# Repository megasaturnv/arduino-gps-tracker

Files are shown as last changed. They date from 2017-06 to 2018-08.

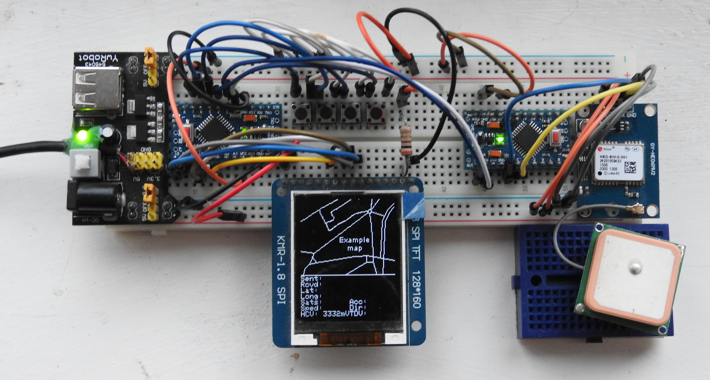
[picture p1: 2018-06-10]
docs/top down view.jpg

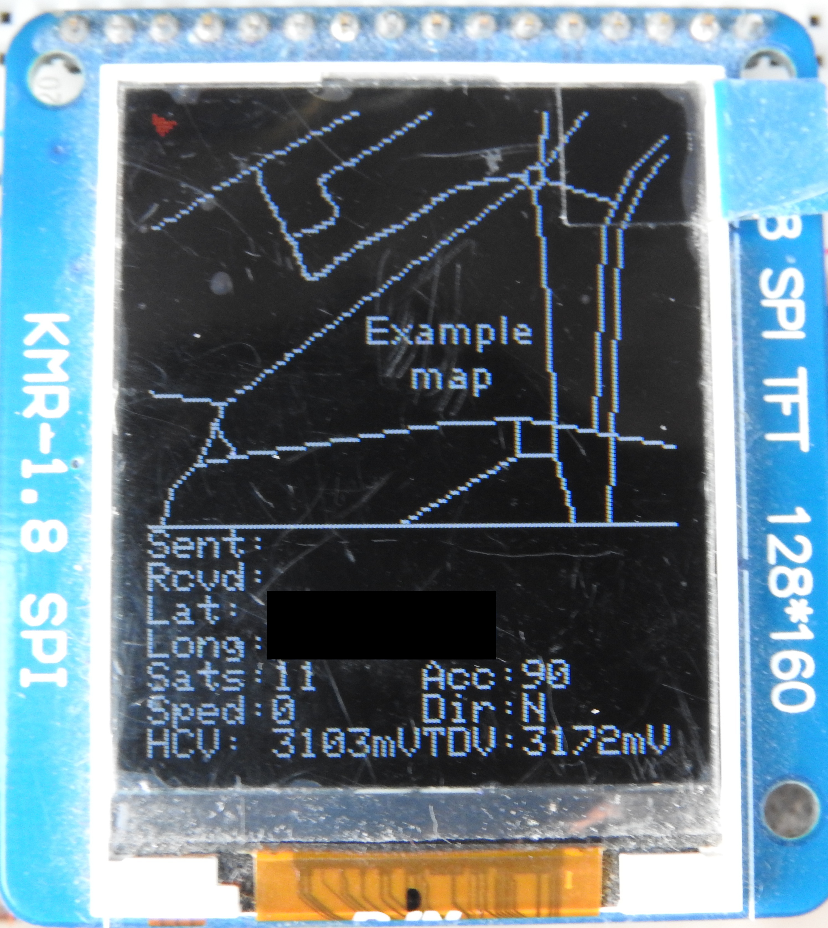
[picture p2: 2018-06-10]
docs/Location marker on Screen.jpg

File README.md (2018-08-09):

# arduino-gps-tracker
## Synopsis
An Arduino-based GPS tracking solution. One Arduino and Ublox Neo-6m (GY-NEO6MV2) GPS module on stripboard / veroboard is used as the GPS tracking device. The other is an Arduino handheld controller which requests information from the tracking device and displays the coordinates, GPS location and location on a map. By default, the display is a 128x160 1.8" TFT LCD but the code can be adapted for other displays. Communication occurs between the two devices with the HC-12 wireless serial communication module. This project can be adapted to use other methods of wireless communication such as the XBee or GSM mobile network. Please make sure the frequency used and transmitting power is legal in your country.



## Description of Arduino handheld controller
The Arduino handheld controller is used by a user to find the location of their GPS tracking device. It is powered by an 18650 Li-ion cell and consists of Li-ion protection and charging circuitry, an Arduino, a 1.8" TFT LCD display, a HC-12 wireless communication module and buttons for requesting various data from the tracking device. When it receives data from the tracking device, the Arduino will interpret the message formtted as \<datatype>:\<CSV of data> into \<data type> and an array of data for each item in \<CSV of data>. Then, the tracker respond in the appropriate way. The messages it understands and the way it responds are listed below:

#### if receive "volts:\[millivolts\]"
Display the tracking device Arduino's VCC voltage on the 1.8" TFT LCD display.

#### if receive "gps:\<latitude>, \<longitude>, \<num of satellites>, \<accuracy>, \<speed>, \<direction>, \<age of data>, \<checksum>"
Display these figures on the 1.8" TFT LCD display.

### Buttons
The buttons on the handheld controller are pulled high by the Arduino's internal pull-up resistors. To activate the button, the pin should be connected to ground. 

### The Arduino pins used to connect to peripherals is shown below:
#define name | Pin no. | Function
--- | --- | ---
SOFTWARE_SERIAL_TX | 2 | For the HC-12 module. Connects to HC-12 RX
SOFTWARE_SERIAL_RX | 3 | For the HC-12 module. Connects to HC-12 TX
CELLVOLTS_BUTTON | 4 | Push button connected to ground. transmit: "cell:volts" to the tracking device
REQUEST_GPS_ONCE_BUTTON | 5 | Push button connected to ground. transmit: "gps:once"
REQUEST_GPS_CONTINUOUS_BUTTON | 6 | Push button connected to ground. transmit: "gps:continuous"
REQUEST_GPS_STOP_BUTTON | 7 | Push button connected to ground. transmit: "gps:stop"
sclk | 13 | Connection to 1.8" TFT LCD screen. Connects to TFT SCK/
mosi | 11 | Connection to 1.8" TFT LCD screen. Connects to TFT SDA/
cs | 10 | Connection to 1.8" TFT LCD screen. Connects to TFT SCS/
dc | A0 | Connection to 1.8" TFT LCD screen. Connects to TFT A0/
rst | A1 | Connection to 1.8" TFT LCD screen. Connects to TFT RESET/

### Showing location on the display's map
*COMING SOON*

### How to create your own maps for the TFT LCD screen
*COMING SOON*

## Description of Arduino GPS tracking device
The Arduino tracking device should be attached to an object which the user wants to track. It is powered by an 18650 Li-ion cell and consists of Li-ion protection and charging circuitry, an Arduino, a Ublox Neo-6m (GY-NEO6MV2) GPS module and a HC-12 wireless communication module. The circuit is built onto a piece of stripboard / veroboard. When powered, the Arduino will go into a light sleep mode. It will wake up when it receives serial data from the HC-12 module. The Arduino will interpret the message formtted as \<datatype>:\<CSV of data> into \<data type> and an array of data for each item in \<CSV of data>. Then, the tracker responds in the appropriate way.

### Kicad designs



### The messages the Arduino GPS tracking device understands and the way it responds are listed below:
#### if receive "cell:volts"
send "cell:\[millivolts\]" where millivolts = voltage of the tracking device Arduino's VCC pin

#### if receive "gps:once"
send "message:received gps once" and try to get GPS coordinates. Then, send coordinates once and go to sleep

#### if receive "gps:continuous"
send "message:received gps continuous" and try to get GPS coordinates. Then, send coordinates every 10 seconds

#### if receive "gps:stopcontinuous"
send "message:gpsstopcontinuous" and then stop sending GPS coordinates continuously

If the tracking device is requested for coordinates, it will try and get its GPS location. If it cannot get a fix after GPS_TIMEOUT milliseconds, the Arduino will send "message:Unable to get GPS fix" to the handheld controller, where it will be displayed on the screen. This functionality can be disabled by setting GPS_TIMEOUT to 0 (#define GPS_TIMEOUT 0).

If no more GPS coordinates are required (after a successful GPS lock with "gps:once" or "gps:stopcontinuous" commmand) or if the Arduino has been on for more than MAX_ON_TIME, go to sleep. MAX_ON_TIME is a failsafe to make sure the Arduino doesn't stay on for more than MAX_ON_TIME milliseconds. This functionality can be disabled by setting MAX_ON_TIME to 0 (#define MAX_ON_TIME 0).

### The Arduino pins used to connect to peripherals is shown below:

Pin description | Pin no. | Function
--- | --- | ---
SERIAL_UART_RX | 0 | For the HC-12 module. Connects to HC-12 TX
SERIAL_UART_TX | 1 | For the HC-12 module. Connects to HC-12 RX

#define name | Pin no. | Function
--- | --- | ---
SOFTWARE_SERIAL_RX | 3 | Software serial RX pin, to be connected to the GPS module's TX
SOFTWARE_SERIAL_TX | 2 | Software serial TX pin, to be connected to the GPS module's RX

## Motivation
I have created this project to be used as a dog tracker, but it can easily track a car and other valuable item.

## Installation
Upload gpsTracker_handheldController to the Arduino which will be used in the handheld controller. Upload gpsTracker_trackingDevice to the Arduino which will be used in the tracking device. Follow the build diagrams and create the stripboard / veroboard circuit board from the KiCAD files to construct the GPS tracking device.

## Libraries used
### Handheld controller
* [Adafruit_GFX](https://github.com/adafruit/Adafruit-GFX-Library)
* [Adafruit_QDTech](https://github.com/zigwart/Adafruit_QDTech) Note my display is QDTech 1.8" 128x160 pixel LCD board using a Samsung S6D02A1 chip, so I need a special library.
* [SPI](https://github.com/arduino/Arduino/tree/master/hardware/arduino/avr/libraries/SPI)
* [SoftwareSerial](https://github.com/arduino/Arduino/tree/master/hardware/arduino/avr/libraries/SoftwareSerial)

### Tracking device
* [avr/power](https://github.com/Synapseware/avr/blob/master/include/avr/power.h)
* [avr/sleep](https://github.com/Synapseware/avr/blob/master/include/avr/sleep.h)
* [SoftwareSerial](https://github.com/arduino/Arduino/tree/master/hardware/arduino/avr/libraries/SoftwareSerial)
* [TinyGPS](http://arduiniana.org/libraries/tinygps/)

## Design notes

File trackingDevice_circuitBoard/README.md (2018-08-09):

# gpsTracker_trackingDevice_circuitBoard
Schematic and circuit board design for the tracking device. Used to create a stripboard / veroboard circuit board.

To be opened with KiCad EDA, a cross platform, free and open source electronics design automation suite.
* http://kicad-pcb.org/
* https://github.com/kicad

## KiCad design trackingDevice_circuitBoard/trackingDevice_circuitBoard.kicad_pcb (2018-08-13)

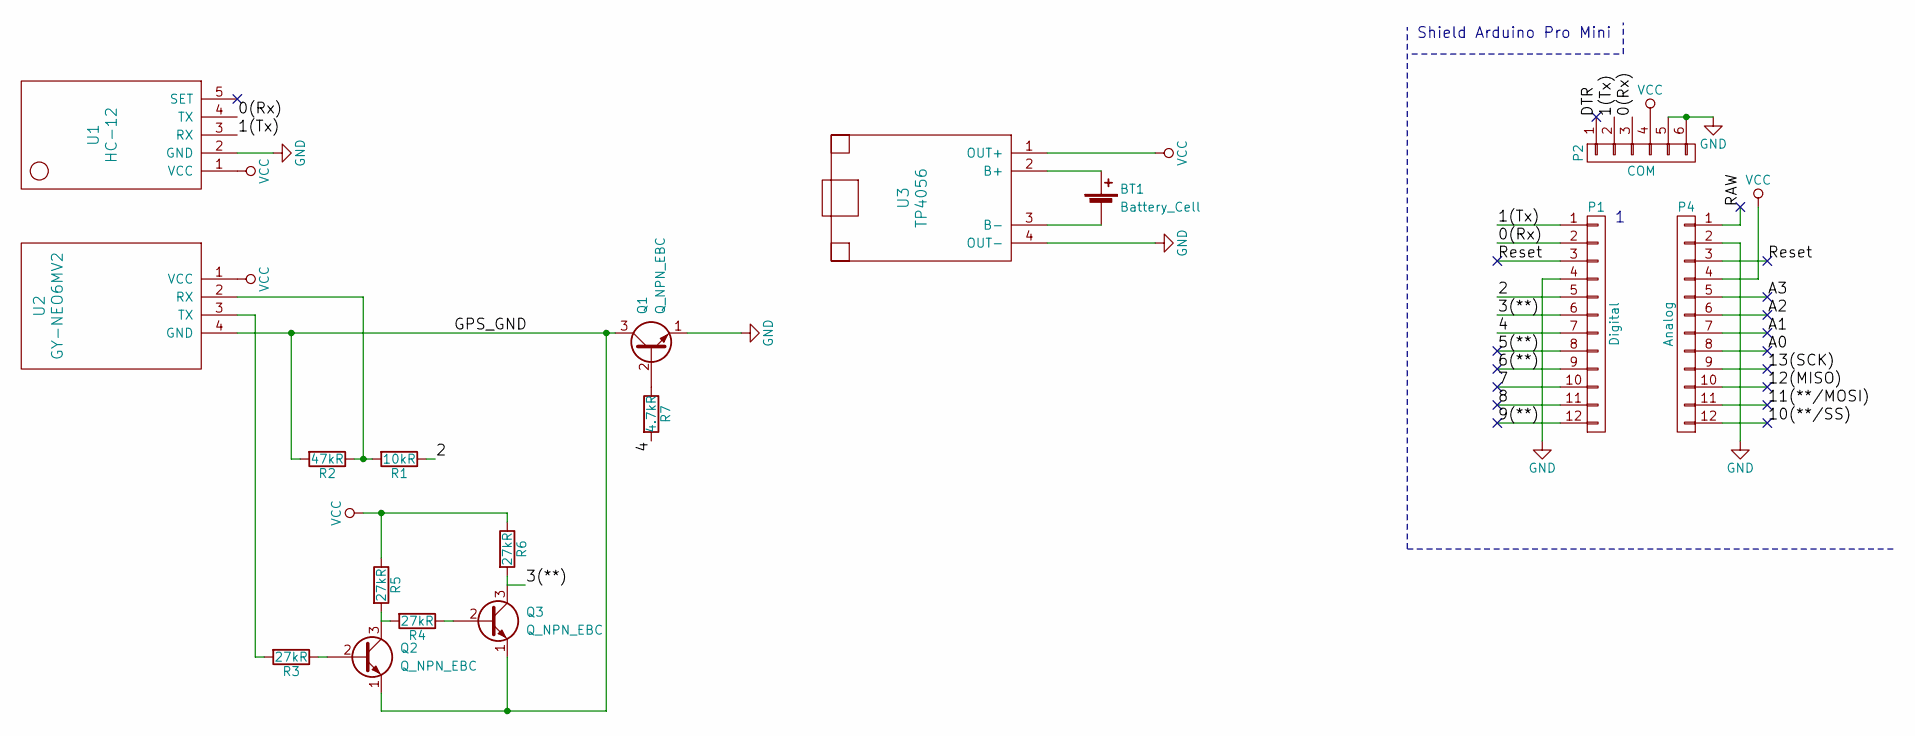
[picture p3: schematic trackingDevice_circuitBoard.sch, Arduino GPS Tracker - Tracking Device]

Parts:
BT1: Battery_Cell; CP_Axial_L67.0mm_D23.0mm_P75.00mm_Horizontal
P1: Digital; Socket_Strip_Straight_1x12_Pitch2.54mm
P2: COM
P4: Analog; Socket_Strip_Straight_1x12_Pitch2.54mm
Q1, Q2, Q3: Q_NPN_EBC; TO-92_Inline_Wide
R1: 10kR; R_Axial_DIN0207_L6.3mm_D2.5mm_P10.16mm_Horizontal
R2: 47kR; R_Axial_DIN0207_L6.3mm_D2.5mm_P10.16mm_Horizontal
R3, R4, R5, R6: 27kR; R_Axial_DIN0207_L6.3mm_D2.5mm_P10.16mm_Horizontal
R7: 4.7kR; R_Axial_DIN0207_L6.3mm_D2.5mm_P15.24mm_Horizontal
U1: HC-12; Socket_Strip_Straight_1x05_Pitch2.54mm
U2: GY-NEO6MV2; Socket_Strip_Straight_1x04_Pitch2.54mm
U3: TP4056; TP4056_with_protection

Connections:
/0(Rx): P1.2, P2.3, U1.4 (TX)
/1(Tx): P1.1, P2.2, U1.3 (RX)
/2: P1.5, R1.1
/3(**): P1.6, Q3.3 (C), R6.2
/4: P1.7, R7.2
/5(**): P1.8
/6(**): P1.9
/7: P1.10
/8: P1.11
/9(**): P1.12
/10(**/SS): P4.12
/11(**/MOSI): P4.11
/12(MISO): P4.10
/13(SCK): P4.9
/A0: P4.8
/A1: P4.7
/A2: P4.6
/A3: P4.5
/GPS_GND: Q1.3 (C), Q2.1 (E), Q3.1 (E), R2.2, U2.4 (GND)
/RAW: P4.1
/Reset: P1.3, P4.3
GND: P1.4, P2.5, P2.6, P4.2, Q1.1 (E), U1.2 (GND), U3.4 (OUT-)
unnamed: BT1.1 (+), U3.2 (B+)
unnamed: BT1.2 (-), U3.3 (B-)
unnamed: Q1.2 (B), R7.1
unnamed: Q2.2 (B), R3.1
unnamed: Q2.3 (C), R4.2, R5.2
unnamed: Q3.2 (B), R4.1
unnamed: R1.2, R2.1, U2.2 (RX)
unnamed: R3.2, U2.3 (TX)
VCC: P2.4, P4.4, R5.1, R6.1, U1.1 (VCC), U2.1 (VCC), U3.1 (OUT+)

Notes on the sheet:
Shield Arduino Pro Mini

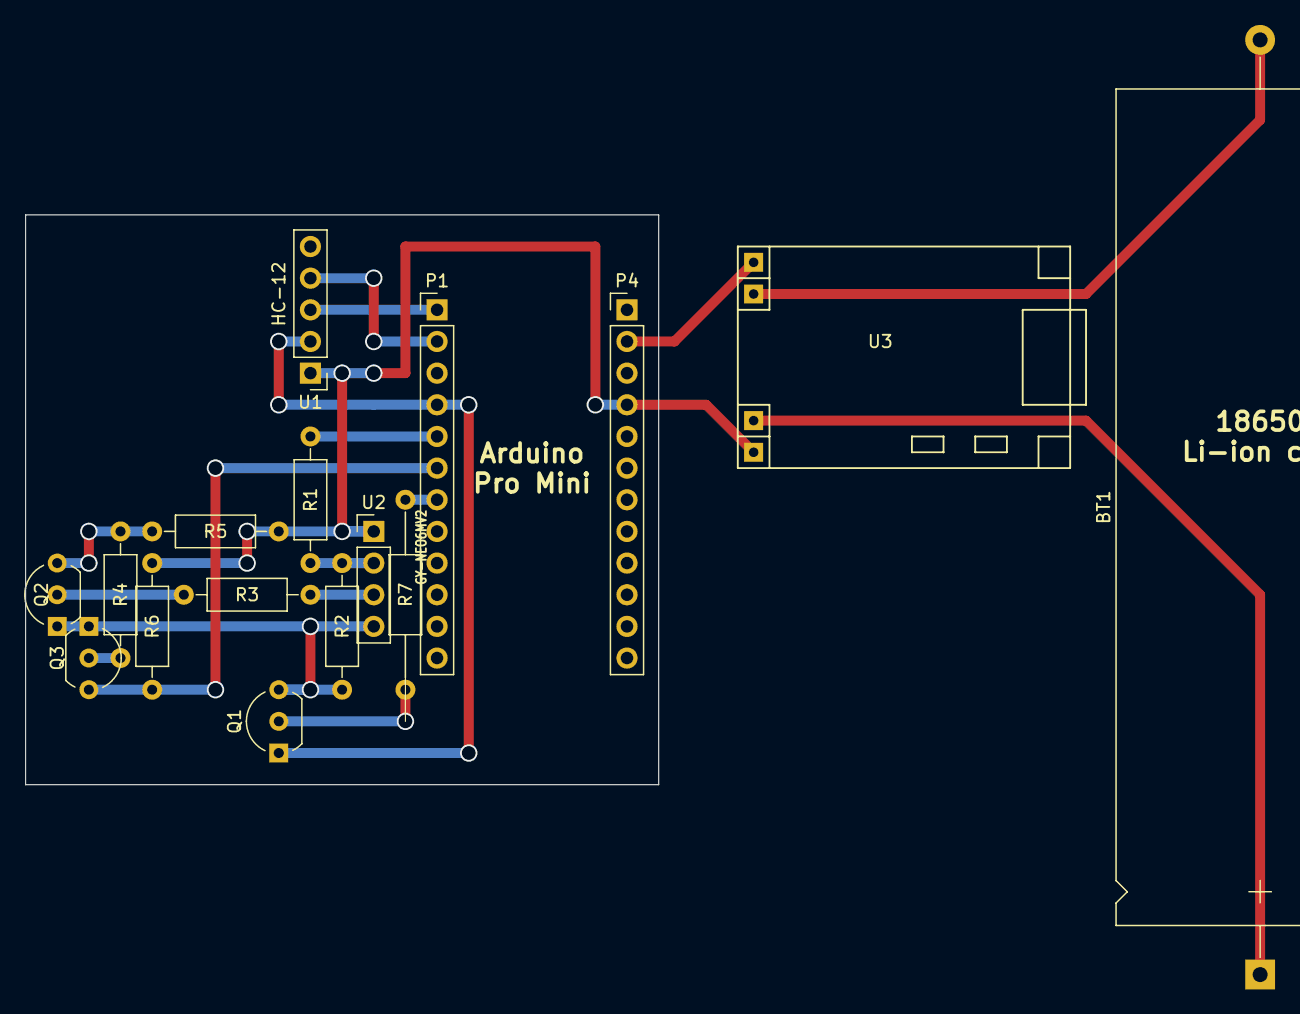
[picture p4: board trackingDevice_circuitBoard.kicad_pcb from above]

Board: 2 copper layers, 50.8 x 45.7 mm, 16 parts (0 on the bottom side), 17 nets.

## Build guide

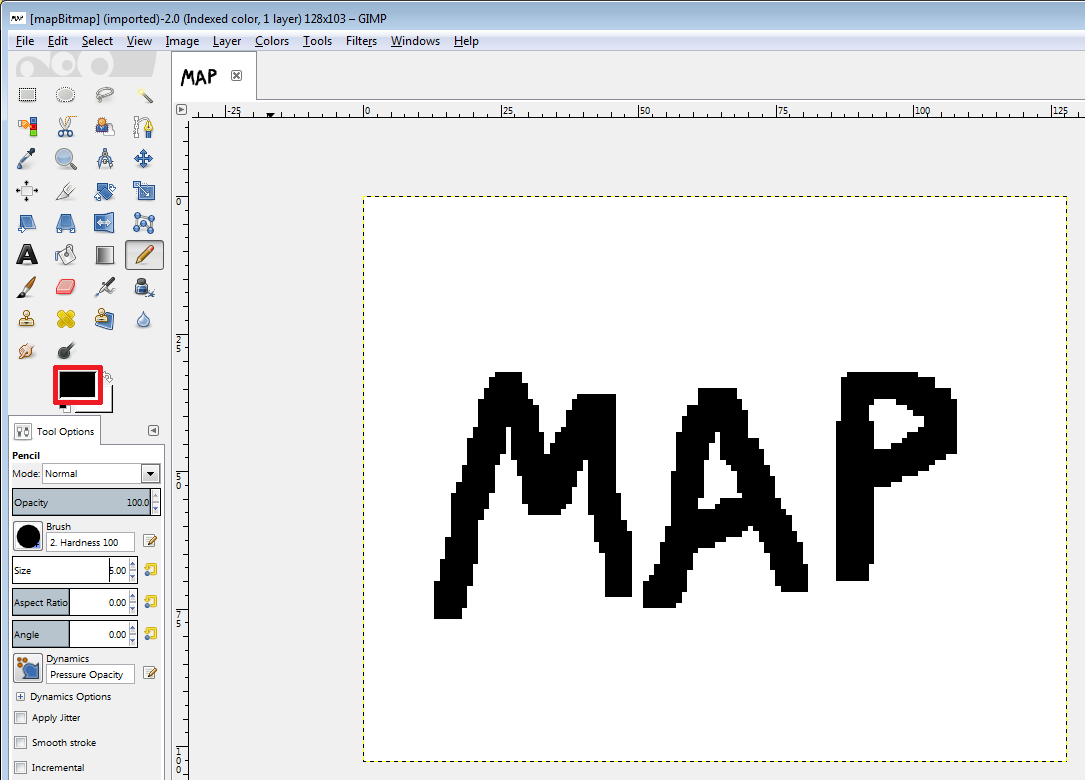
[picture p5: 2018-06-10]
maps/Step3 Draw your map.png

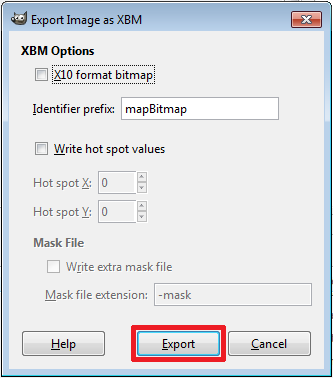
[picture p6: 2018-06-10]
maps/Step6 Export Settings2.png

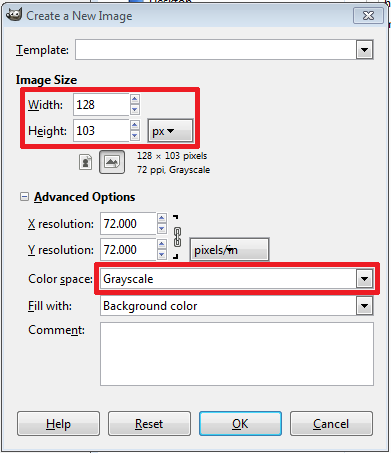
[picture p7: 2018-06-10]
maps/Step2 New Image Settings.png

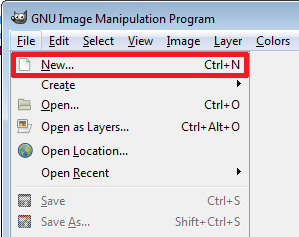
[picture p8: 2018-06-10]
maps/Step1 New Image.png

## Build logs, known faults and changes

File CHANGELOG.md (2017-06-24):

# arduino-gps-tracker changelog
## v0.1
* Initial release
* Handheld controller: Added the handheld controller under "gpsTracker_handheldController". It can display sent messages, received messages, latitude, longitude, number of satellites, accuracy, speed, direction, age of data and the checksum value.
* Handheld controller: Added map to TFT LCD screen. Map is not yet functional.
* Tracking device: Added the GPS tracker under "gpsTracker_trackingDevice". It can get GPS coordinates and transmit them when requested.
* Tracking device: Added code so the Arduino can go into a light sleep and wake up when serial data in the buffer. Sleep occurs after the Arduino has finished its task, couldn't receive coordinates before GPS_TIMEOUT milliseconds or, as a failsafe, the Arduino will sleep if it has been on for more than MAX_ON_TIME milliseconds as long as it hasn't received any messages from the handheld controller during this time.

## v0.2
* Handheld controller: Added ability to show the current location on the map
* Handheld controller: The program requires the max and min values of latitude and longitude covered by the map
* Handheld controller: Added 3 functions: clearTFTMAP(), drawTFTMap() and displayLocationOnMap(currentLatitude,currentLongitude)
* Handheld controller: Removed debugging code from gpsTracker_handheldController which printed to the UART Serial port
* Handheld controller: Renamed some functions and variables for clarity
* Tracking device: Renamed some functions and variables for clarity
* Tracking device: Tweaked delay values for better timing

## v0.2.1
* Handheld controller: Added clear map button on pin 8

## v0.3
* Handheld controller: Renamed LED_BUILTIN to LED_PIN and changed value to pin 9. Pin 13 is used by the TFT LCD screen
* Handheld controller: Changed the way location is drawn on the map (from 5 pixels in a '+' shape to a single pixel)
* Handheld controller: Added functionality to draw a green line to represent the tracker's location history
* Handheld controller test code: Added test code for drawing arrows on the screen
* Handheld controller: Added ability to draw an arrow at the edge of the screen if the tracker is outside the map
* Tracking device: Increased default MAX_ON_TIME to 1 hour

## v0.3.1
* Handheld controller: Added more constants under #define, for custom configurations

## v0.3.2
* Tracking device: Added KiCad circuit board files to "/gpsTracker_trackingDevice_circuitBoard/"

## v0.3.3
* Tracking device: Added more configuration constants
* Tracking device: Fixed bug where Arduino should stay awake to report continuous GPS data but would instead sleep if any message was received on the UART serial buffer
* Tracking device: Added more code comments

## v0.3.4
* Tracking device: Added ability for Arduino to control the GPS's power through pin 4. An N-channel MOSFET is required. See circuit diagram in gpsTracker_trackingDevice_circuitBoard/
* Tracking device: Updated OutputPowerSavingPins[] array to reflect changes

## v0.4
* Tracking device: Added readVcc() function which allows the Arduino to read its own Vcc input voltage. This will allow the user to know the charge state of the Li-ion cell(s)
* Tracking device: Tracking device will return cell charge in mV as: "cell:0000mV" when it receives "cell:volts"
* Tracking device: Removed "ping" message recognition code
* Handheld controller: Replaced ping button with cell voltage button
* Handheld controller: Removed "ping" message recognition code
* Handheld controller: Removed "age" and "check" areas from screen to make room for HCV:0000mV (Handheld controller voltage) and TDV:0000mV (Tracking device voltage)
* Handheld controller: Moved bottom-right values to the left by 1 character (6 pixels) to give more room for values
* Handheld controller: Modified clearTFTGPS(). Added clearTFT_HCV() and clearTFT_TDV()
* Handheld controller: Added code so the handheld controller can request and display the Vcc voltage of the GPS tracking device
* Handheld controller: Also added readVcc() function which allows the Arduino to read its own Vcc input voltage
* Handheld controller: Added code so the handheld controller reads its own Vcc input voltage every HCV_READVCC_INTERVAL in milliseconds and displays value on TFT screen. default HCV_READVCC_INTERVAL is 30000 ms
* Handheld controller: Removed unused functions
* Tracking device: Renamed GPS_DATA_TRANSMIT_FREQUENCY to GPS_DATA_TRANSMIT_INTERVAL for clarity
* Tracking device: Removed unused functions

## v0.4.1 (Current release)
* Handheld controller: Renamed files and folders to remove "gpsTracker_..."
* Tracking device: Renamed files and folders to remove "gpsTracker_..."

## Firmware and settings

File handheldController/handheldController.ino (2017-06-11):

#define MAP_WIDTH_PX 128 // Height of the map on the screen in pixels
#define MAP_HEIGHT_PX 103 // Width of the map on the screen in pixels

#define MAP_MIN_LAT  51.49933 // Bottom of map
#define MAP_MAX_LAT  51.50922 // Top of map
#define MAP_MIN_LONG -0.14816 // Left of map
#define MAP_MAX_LONG -0.12059 // Right of map

#define COLOUR_BACKGROUND QDTech_BLACK // Display background colour
#define COLOUR_BITMAP QDTech_WHITE // Colour of the map
#define COLOUR_TEXT QDTech_WHITE // Colour of the text
#define COLOUR_MAP_BORDER QDTech_WHITE // The colour used for the line which separates the map from the text below
#define COLOUR_LOCATION_CURRENT QDTech_RED // Colour of the pixel used to represent the current location on the map
#define COLOUR_LOCATION_HISTORY QDTech_GREEN // The colour of the line showing location history

#define TFT_ORIENTATION 0 // Orientation of TFT LCD 1.8" screen. 0 = Portrait, 1 = Landscape
#define UART_SERIAL_BAUD 1200 // Baud rate of the UART serial port (used for debugging)
#define SS_SERIAL_BAUD 1200 // Baud rate of the software serial port (used for wireless communication)
#define HCV_READVCC_INTERVAL 30000 // Handheld controller readVcc() interval in ms

#define CELLVOLTS_BUTTON 4
#define REQUEST_GPS_ONCE_BUTTON 5
#define REQUEST_GPS_CONTINUOUS_BUTTON 6
#define REQUEST_GPS_STOP_BUTTON 7
#define REDRAW_MAP_BUTTON 8
#define LED_PIN 9

#define sclk 13 // Don't change
#define mosi 11 // Don't change
#define cs   10
#define dc   A0
#define rst  A1 // You can also connect this to the Arduino reset

#define _SS_MAX_RX_BUFF 128
#define SOFTWARE_SERIAL_RX 3
#define SOFTWARE_SERIAL_TX 2

#include <Adafruit_GFX.h>    // Core graphics library
#include <Adafruit_QDTech.h> // Hardware-specific library
#include <SPI.h>
#include <SoftwareSerial.h>

//Include the bitmap of the map. Location of the GPS tracker is drawn on the map
#include "mapBitmap.h"

SoftwareSerial ss(SOFTWARE_SERIAL_RX, SOFTWARE_SERIAL_TX); // For HC-12 wireless communication module.

Adafruit_QDTech tft = Adafruit_QDTech(cs, dc, rst);

int previousCoordinates[] = { -1, -1};
unsigned long printHCVTargetTime;

void transmit(String datatype, String data) {
  setCursorLine(5, 13);
  tft.print(datatype + ":" + data);
  ss.print(datatype + ":" + data + "\n");
  delay(1000);
  clearTFTTransmitted();
}

bool digitalReadDebounce(int pin) { //Digital read a pin with software debounce
  if (digitalRead(pin) == LOW) {
    delay(50);
    bool debounceRunning = true;
    while (debounceRunning) {
      if (digitalRead(pin) == HIGH) {
        debounceRunning = false;
      }
    }
    delay(50);
    return true;
  }
  return false;
}

void setCursorLine(unsigned int lineX, unsigned int lineY) {
  //Screen is 128px x 160px
  //Characters are 6px x 8px
  //(126px used for chars) x 160px  =  21 x 20 characters
  tft.setCursor(lineX * 6, lineY * 8);
}

void clearTFTGPS() {
  //  fillRect(x0,    y0,     w,      h,     colour)
  tft.fillRect(5 * 6, 15 * 8, 17 * 6, 2 * 8, COLOUR_BACKGROUND); //clear lat and long
  tft.fillRect(5 * 6, 17 * 8, 6 * 6, 2 * 8, COLOUR_BACKGROUND); //clear bottom left values, except the bottom row - which is for cell voltage
  tft.fillRect(15 * 6, 17 * 8, 7 * 6, 2 * 8, COLOUR_BACKGROUND); //clear bottom right values, except the bottom row - which is for cell voltage
}

void clearTFT_HCV() { // Clear handheld controller voltage
  tft.fillRect(5 * 6, 19 * 8, 6 * 6, 1 * 8, COLOUR_BACKGROUND); //clear HCV value (handheld controller voltage)
}

void clearTFT_TDV() { // Clear tracking device voltage
  tft.fillRect(15 * 6, 19 * 8, 7 * 6, 1 * 8, COLOUR_BACKGROUND); //clear TDV value (tracking device voltage)
}

void clearTFTReceived() {
  tft.fillRect(5 * 6, 14 * 8, 17 * 6, 1 * 8, COLOUR_BACKGROUND); //clear the received text
}

void clearTFTTransmitted() {
  tft.fillRect(5 * 6, 13 * 8, 17 * 6, 1 * 8, COLOUR_BACKGROUND); // Clear the transmitted text
}

void clearTFTMap() {
  tft.fillRect(0, 0, 128, 103, COLOUR_BACKGROUND); //clear the map drawn on the TFT screen
}

void drawTFTMap() {
  tft.drawXBitmap(0, 0, mapBitmap, MAP_WIDTH_PX, MAP_HEIGHT_PX, COLOUR_BITMAP); //Draw bitmap image
}

void drawArrow(byte screenX, byte screenY, byte dir) {
  //dir is the direction of the arrow. North-West is 0, North is 1, North east is 2 such that:
  //  NW  N  NE     0 1 2
  //   W     E   =  7   3
  //  SW  S  SE     6 5 4

  //Note: Dir could be inferred from screenX and screenY...
  switch (dir) {
    case 0: //NW
      //  fillTriangle(x0,      y0,      x1,          y1,          x2,          y2,          colour)
      tft.fillTriangle(screenX, screenY, screenX + 2, screenY + 5, screenX + 5, screenY + 2, COLOUR_LOCATION_CURRENT);
      break;
    case 1: //N
      tft.fillTriangle(screenX, screenY, screenX - 2, screenY + 5, screenX + 2, screenY + 5, COLOUR_LOCATION_CURRENT);
      break;
    case 2: //NE
      tft.fillTriangle(screenX, screenY, screenX - 2, screenY + 5, screenX - 5, screenY + 2, COLOUR_LOCATION_CURRENT);
      break;
    case 3: //E
      tft.fillTriangle(screenX, screenY, screenX - 5, screenY - 2, screenX - 5, screenY + 2, COLOUR_LOCATION_CURRENT);
      break;
    case 4: //SE
      tft.fillTriangle(screenX, screenY, screenX - 2, screenY - 5, screenX - 5, screenY - 2, COLOUR_LOCATION_CURRENT);
      break;
    case 5: //S
      tft.fillTriangle(screenX, screenY, screenX + 2, screenY - 5, screenX - 2, screenY - 5, COLOUR_LOCATION_CURRENT);
      break;
    case 6: //SW
      tft.fillTriangle(screenX, screenY, screenX + 2, screenY - 5, screenX + 5, screenY - 2, COLOUR_LOCATION_CURRENT);
      break;
    case 7: //W
      tft.fillTriangle(screenX, screenY, screenX + 5, screenY + 2, screenX + 5, screenY - 2, COLOUR_LOCATION_CURRENT);
      break;
  }
}

void displayLocationOnMap(float currentLatitude, float currentLongitude) {
  //Relative X position on map between 0 and 1
  float relativeXPosOnMap = (currentLongitude - MAP_MIN_LONG) / (MAP_MAX_LONG - MAP_MIN_LONG);
  //Calculate screen X coordinates for current GPS location
  int screenXPos = relativeXPosOnMap * float(MAP_WIDTH_PX);

  //Relative Y position on map between 0 and 1
  //1.0 - the relative Position because Y-coordinates on screen are inversed relative to latitude (and the standard 'Cartesian' coordinate system
  //i.e. Y-coordinate increases as you go down the screen. Latitude increases as you go up the screen.
  //There are many ways to fix this problem. e.g. change MAP_MIN_LAT to MAP_MAX_LAT or switching the denominators should have the same result
  float relativeYPosOnMap = 1.0 - ((currentLatitude - MAP_MIN_LAT) / (MAP_MAX_LAT - MAP_MIN_LAT));
  //Calculate screen Y coordinates for current GPS location.
  int screenYPos = relativeYPosOnMap * float(MAP_HEIGHT_PX);

  //For debugging
  //Serial.println("RelXPos: " + String(relativeXPosOnMap));
  //Serial.println("RelYPos: " + String(relativeYPosOnMap));
  //Serial.println("MapXPos: " + String(screenXPos));
  //Serial.println("MapYPos: " + String(screenYPos));

  //if tracker is on-screen
  if (relativeXPosOnMap >= 0 && relativeXPosOnMap <= 1 && relativeYPosOnMap >= 0 && relativeYPosOnMap <= 1) {
    //Draw pixel on map at previous coordinates for plot of location history
    tft.drawPixel(previousCoordinates[0], previousCoordinates[1], COLOUR_BACKGROUND); //Clear the pixel first
    tft.drawPixel(previousCoordinates[0], previousCoordinates[1], COLOUR_LOCATION_HISTORY);

    //Draw pixel on map at current location
    tft.drawPixel(screenXPos, screenYPos, COLOUR_BACKGROUND); //Clear the pixel first
    tft.drawPixel(screenXPos, screenYPos, COLOUR_LOCATION_CURRENT);

    //Uncomment to draw a '+' of pixels around location (May break line on graph showing tracker's location history)
    //tft.drawPixel(screenXPos + 1, screenYPos    , COLOUR_LOCATION_CURRENT);
    //tft.drawPixel(screenXPos - 1, screenYPos    , COLOUR_LOCATION_CURRENT);
    //tft.drawPixel(screenXPos    , screenYPos + 1, COLOUR_LOCATION_CURRENT);
    //tft.drawPixel(screenXPos    , screenYPos - 1, COLOUR_LOCATION_CURRENT);

    //Uncomment to draw a 'x' of pixels around location (May break line on graph showing tracker's location history)
    //tft.drawPixel(screenXPos-1, screenYPos-1, COLOUR_LOCATION_CURRENT);
    //tft.drawPixel(screenXPos-1, screenYPos+1, COLOUR_LOCATION_CURRENT);
    //tft.drawPixel(screenXPos+1, screenYPos+1, COLOUR_LOCATION_CURRENT);
    //tft.drawPixel(screenXPos+1, screenYPos-1, COLOUR_LOCATION_CURRENT);

    //Set previousCoordinates to current location for next time
    previousCoordinates[0] = screenXPos;
    previousCoordinates[1] = screenYPos;

    ////if tracker is off-screen////
    ////corners of map. i.e. position is completely outside the map's boundaries
    //if tracker is top-left
  } else if (relativeXPosOnMap < 0 && relativeYPosOnMap < 0) {
    drawArrow(0, 0, 0);
    //if tracker is top-right
  } else if (relativeXPosOnMap > 1 && relativeYPosOnMap < 0) {
    drawArrow(MAP_WIDTH_PX, 0, 2);
    //if tracker is bottom-right
  } else if (relativeXPosOnMap > 1 && relativeYPosOnMap > 1) {
    drawArrow(MAP_WIDTH_PX, MAP_HEIGHT_PX - 1, 4);
    //if tracker is bottom-left
  } else if (relativeXPosOnMap < 0 && relativeYPosOnMap > 1) {
    drawArrow(0, MAP_HEIGHT_PX - 1, 6);

    ////edges of map. i.e. position is outside the map in one axis but within the map on the other axis
    //if tracker is top-middle
  } else if (relativeXPosOnMap >= 0 && relativeXPosOnMap <= 1 && relativeYPosOnMap < 0) {
    drawArrow(screenXPos, 0, 1);
    //if tracker is middle-right
  } else if (relativeXPosOnMap > 1 && relativeYPosOnMap <= 1 && relativeYPosOnMap >= 0) {
    drawArrow(MAP_WIDTH_PX, screenYPos, 3);
    //if tracker is bottom-middle
  } else if (relativeXPosOnMap >= 0 && relativeXPosOnMap <= 1 && relativeYPosOnMap > 1) {
    drawArrow(screenXPos, MAP_HEIGHT_PX - 1, 5);
    //if tracker is middle-left
  } else if (relativeXPosOnMap < 0 && relativeYPosOnMap <= 1 && relativeYPosOnMap >= 0) {
    drawArrow(0, screenYPos, 7);
  }
}

long readVcc() {
  // Function to read Arduino's Vcc voltage.
  // Inspiration taken from https://code.google.com/archive/p/tinkerit/wikis/SecretVoltmeter.wiki
  // For ATMEGA168 and ATMEGA328 where the internal reference voltage is 1.1 volts. i.e Arduino Uno, nano and Pro Mini should work fine
  // Internal reference voltage for the ATMEGA8 is 2.56 volts, so it should be easy to modify this code for the ATMEGA8
  // The Arduino Mega has two internal voltage references at 1.1v and 2.56v. There's a chance this code could changed to work with the Arduino Mega
  // The voltage is returned in millivolts. So 5000 is 5V, 3300 is 3.3V

  long result;
  // Read 1.1V reference against AVcc
  ADMUX = _BV(REFS0) | _BV(MUX3) | _BV(MUX2) | _BV(MUX1);
  delay(2); // Wait for Vref to settle
  ADCSRA |= _BV(ADSC); // Convert
  while (bit_is_set(ADCSRA, ADSC));
  result = ADCL;
  result |= ADCH << 8;
  result = 1126400L / result; // Back-calculate AVcc in mV
  return result;
}

void setup() {
  pinMode(LED_PIN, OUTPUT);
  digitalWrite(LED_PIN, HIGH);

  pinMode(CELLVOLTS_BUTTON, INPUT_PULLUP);
  pinMode(REQUEST_GPS_ONCE_BUTTON, INPUT_PULLUP);
  pinMode(REQUEST_GPS_CONTINUOUS_BUTTON, INPUT_PULLUP);
  pinMode(REQUEST_GPS_STOP_BUTTON, INPUT_PULLUP);
  pinMode(REDRAW_MAP_BUTTON, INPUT_PULLUP);

  //Serial.begin(UART_SERIAL_BAUD); //For debugging
  ss.begin(SS_SERIAL_BAUD); //For HC-12 wireless communication module

  tft.init();
  tft.setRotation(TFT_ORIENTATION);
  tft.fillScreen(COLOUR_BACKGROUND);
  tft.setTextWrap(false);
  tft.setCursor(0, 0);
  tft.setTextColor(COLOUR_TEXT);
  tft.setTextSize(1);

  //DRAW BITMAP IMAGE AND PRINT VALUE TITLES
  drawTFTMap();
  tft.drawFastHLine(0, 103, 128, COLOUR_MAP_BORDER); //Note: draw on line 103, which is the 104th line
  setCursorLine(0, 13); //Print titles for values
  tft.println("Sent:");
  tft.println("Rcvd:");
  tft.println("Lat: ");
  tft.println("Long:");
  tft.print("Sats:");
  setCursorLine(11, 17);
  tft.println("Acc:");
  tft.print("Sped:");
  setCursorLine(11, 18);
  tft.println("Dir:");
  //  tft.print("Age:");
  //  setCursorLine(11, 19);
  //  tft.print("Chck:");
  tft.print("HCV:");
  setCursorLine(11, 19);
  tft.print("TDV:");

  digitalWrite(LED_PIN, LOW);
}

void loop() {
  if (printHCVTargetTime < millis()) {
    clearTFT_HCV(); // Clear any old tracking device voltage values
    setCursorLine(5, 19); // Move cursor
    tft.print(String(readVcc()) + "mV"); // Print voltage in mV
    printHCVTargetTime = millis() + HCV_READVCC_INTERVAL;
  }
  if (digitalReadDebounce(CELLVOLTS_BUTTON)) {
    transmit("cell", "volts");
  }
  if (digitalReadDebounce(REQUEST_GPS_ONCE_BUTTON)) {
    transmit("gps", "once");
  }
  if (digitalReadDebounce(REQUEST_GPS_CONTINUOUS_BUTTON)) {
    transmit("gps", "continuous");
  }
  if (digitalReadDebounce(REQUEST_GPS_STOP_BUTTON)) {
    transmit("gps", "stop");
  }
  if (digitalReadDebounce(REDRAW_MAP_BUTTON)) {
    clearTFTMap(); //Clear the map
    drawTFTMap();  //Re-draw the map
  }

  if (ss.available() > 0) {
    digitalWrite(LED_PIN, HIGH);
    delay(2000);
    //// PROCESSING INCOMING SERIAL DATA from "<datatype>:<csv of data>" INTO 'datatype' AND 'datacsvarray' ////
    //Read the incoming byte:
    String receivedSerialString = ss.readStringUntil('\n');
    setCursorLine(5, 14);
    tft.print(String(receivedSerialString));

    //For debugging
    //Serial.println("received: " + receivedSerialString);
    //Serial.println("length: " + String(sizeof(receivedSerialString)));
    //if (ss.overflow()) {
    //  Serial.println("SoftwareSerial overflow!");
    //} else {
    //  Serial.println("no SoftwareSerial overflow!");
    //}

    //Split receivedSerialString into datatype and data
    int indexofcolon = receivedSerialString.indexOf(":");
    int lengthofstring = receivedSerialString.length();
    String datatype = "";
    if (indexofcolon == -1) {
      //Transmit("message", "error - no colon in string");
      delay(100); //Do nothing
    } else if (indexofcolon != 0 && indexofcolon != lengthofstring - 1) {
      datatype = receivedSerialString.substring(0, indexofcolon);
      String datacsv = receivedSerialString.substring(indexofcolon + 1);
      int indexofcomma = datacsv.indexOf(",");
      //For every character in datacsv, if it is a comma add 1 to commacount
      //If not a comma then add 0 to commacount (so commacount doesn't increase)
      int i, commacount;
      for (i = 0, commacount = 0; datacsv[i]; i++) {
        commacount += (datacsv[i] == ',');
      }
      //Create an array with 1 more element than the amount of commas
      //e.g. "1,2,3" has 2 commas and 3 pieces of information
      String datacsvarray[commacount + 1];
      //For the amount of commas+1 in datacsv:
      for (int i = 0; i < commacount + 1; i++) {
        //if there's a comma in datacsv
        if (datacsv.indexOf(",") > -1) {
          //i's position in datacsvarray is set to the string between the start of datacsv and the next comma
          datacsvarray[i] = datacsv.substring(0, datacsv.indexOf(","));
          //The string between the start of datacsv up to and including the next comma is removed from the datacsv
          datacsv.remove(0, datacsv.indexOf(",") + 1);
        } else {
          //i's position in datacsvarray is set to datacsv. This happens once at the end of the for loop when all commas have been removed from datacsv
          datacsvarray[i] = datacsv;
          //For consistency, delete the reset of datacsv
          datacsv.remove(0);
        }
      }

      //For debugging
      //Serial.println("data type: " + datatype);
      //Serial.println("Comma count: " + String(commacount));
      //Serial.println("sizeof datacsvarray: " + String(sizeof(datacsvarray)));
      //for (int i = 0; i <= commacount; i++) {
      //  Serial.print("Data " + String(i) + " " + datacsvarray[i]);
      //  Serial.println(",");
      //}
      //// PROCESSING 'datatype' AND 'datacsvarray' ////
      if (datatype == "cell") {
        clearTFT_TDV(); // Clear any old tracking device voltage values
        setCursorLine(15, 19); // Move cursor
        tft.print(datacsvarray[0]); // Print voltage in mV
      } else if (datatype == "gps") {
        //data = "latitude,longitude,num of satellites,accuracy,speed,direction,age of data,checksum"
        clearTFTGPS();

        setCursorLine(5, 15);
        tft.print(datacsvarray[0]); //latitude
        setCursorLine(5, 16);
        tft.print(datacsvarray[1]); //longitude
        setCursorLine(5, 17);
        tft.print(datacsvarray[2]); //num of satellites
        setCursorLine(15, 17);
        tft.print(datacsvarray[3]); //accuracy
        setCursorLine(5, 18);
        tft.print(datacsvarray[4]); //speed
        setCursorLine(15, 18);
        tft.print(datacsvarray[5]); //direction
        //setCursorLine(5, 19);
        //tft.print(datacsvarray[6]); //age of data
        //setCursorLine(15, 19);
        //tft.print(datacsvarray[7]); //checksum

        if (commacount != 7) { // If incorrect number of commas received, show it in bottom right corner of screen
          setCursorLine(20, 19);
          tft.print(commacount);
        }

        clearTFTMap(); //Clear the map
        drawTFTMap();  //Re-draw the map
        displayLocationOnMap(datacsvarray[0].toFloat(), datacsvarray[1].toFloat()); //Display current location on the map. Arguments are (float latitude, float longitude)

      } else if (datatype == "message") {
        clearTFTReceived(); //message is written to the same area of the screen as received text, so this is cleared first
        setCursorLine(5, 14);
        tft.print(datacsvarray[0]); //For messages with only one piece of data and therefore one item in datacsvarray[]
        /*for (int i = 0; i <= commacount; i++) { //For messages with multiple items in datacsvarray[] (not used)
              tft.print(datacsvarray[i]);
              tft.print(",");
            }*/
        delay(1000); //Delay for a second so the user can read the message
      } else {
        //transmit("message", "message datatype not understood");
        delay(100); //Do nothing
      }
    } else {
      transmit("message", "nothing on one side of colon character");
    }
    delay(200);
    clearTFTReceived();
    digitalWrite(LED_PIN, LOW);
  }
}

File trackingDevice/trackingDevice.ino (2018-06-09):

#include <avr/power.h>
#include <avr/sleep.h>
#include <SoftwareSerial.h>
#include <TinyGPS.h>
//https://github.com/mikalhart/TinyGPS

#define UART_SERIAL_BAUD 1200 // Baud rate of the UART serial port (used for wireless communication)
#define SS_SERIAL_BAUD 9600 // Baud rate of the software serial port (used for GPS module communication)
#define GPS_TIMEOUT 0 // Amount of time in ms until the Arduino gives up trying to receive a GPS signal. Set to 0 to disable timeout
#define MAX_ON_TIME 3600000 // Failsafe maximum on-time in ms for the Arduino. MAX_ON_TIME will reset when awaking or if the arduino receives data in its serial buffer. Set to 0 to disable failsafe sleep
#define GPS_DATA_TRANSMIT_INTERVAL 15000 //How often data is transmitted to the handheld controller when gpsRequestMode == 2 (Continuous GPS data transmission)
#define SOFTWARE_SERIAL_RX 3 // Software serial RX pin, to be connected to the GPS module's TX
#define SOFTWARE_SERIAL_TX 2 // Software serial TX pin, to be connected to the GPS module's RX
#define GPS_POWER_PIN 4 // Control power to the GPS module via a transistor

TinyGPS gps;
SoftwareSerial ss(SOFTWARE_SERIAL_RX, SOFTWARE_SERIAL_TX); // For GPS module

// Unused pins that should be set as outputs (this slightly reduces the amount of power used by the Arduino).
// Pin 14 = A0, 15 = A2 etc to 19=A5. DO NOT plug anything into these pins.
// ################################################################
// #### YOU MUST UPDATE THIS ARRAY IF ANY PIN CHANGES ARE MADE ####
// ################################################################
const byte OutputPowerSavingPins[] = {5, 6, 7, 8, 9, 10, 11, 12, 13, 14, 15, 16, 17, 18, 19};

unsigned long startMillis, targetTime;

bool requestSleep = true;
byte gpsRequestMode = 0;
// The meanings of gpsRequestMode is listed below
// 0 = handheld is not requesting GPS data. Arduino should go into sleep mode
// 1 = handheld is requesting GPS data to be transmitted once. Arduino will then set gpsRequestMode to 0 and sleep
// 2 = handheld is requesting continuous transmission of GPS data

void transmit(String datatype, String data) {
  Serial.print(datatype + ":" + data + "\n");
  delay(1000); //TEMP - testing
}

void ArduinoSleep() {
  // Based on code from http://playground.arduino.cc/Learning/ArduinoSleepCode and http://rubenlaguna.com/wp/2008/10/15/arduino-sleep-mode-waking-up-when-receiving-data-on-the-usart/

  gpsRequestMode = 0; // Make sure gpsRequestMode is 0 so it sleeps if the arduino is woken by an invalid serial message
  requestSleep = false; // Set requestSleep to false so the Arduino doesn't try to sleep again
  ss.end(); // Stop software serial (it was waking up the arduino for some reason
  digitalWrite(GPS_POWER_PIN, LOW); // Turn off GPS module

  transmit("message", "sleeping");
  delay(2000); // TEMP gives extra time for message to exit serial buffer

  set_sleep_mode(SLEEP_MODE_IDLE); // Sleep mode is set here

  sleep_enable(); // Enables the sleep bit in the mcucr register so sleep is possible. just a safety pin

  power_adc_disable();
  power_spi_disable();
  power_timer0_disable();
  power_timer1_disable();
  power_timer2_disable();
  power_twi_disable();

  PRR = PRR | 0b00100000; // Disable the 8-bit timer http://playground.arduino.cc/Learning/ArduinoSleepCode

  sleep_mode(); // Here the device is actually put to sleep!!

  // THE PROGRAM CONTINUES FROM HERE AFTER WAKING UP

  sleep_disable(); // First thing after waking from sleep: disable sleep...

  PRR = PRR & 0b00000000; // Re-enable the 8-bit timer. The PRR refers to the Power Reduction Register.

  power_all_enable();

  digitalWrite(GPS_POWER_PIN, HIGH); // Turn on GPS module
  delay(500); // Give GPS module half a second to turn on
  ss.begin(SS_SERIAL_BAUD); // Begin software serial for GPS module communication
  startMillis = millis(); // Record startMillis
}

long readVcc() {
  // Function to read Arduino's Vcc voltage.
  // Inspiration taken from https://code.google.com/archive/p/tinkerit/wikis/SecretVoltmeter.wiki
  // For ATMEGA168 and ATMEGA328 where the internal reference voltage is 1.1 volts. i.e Arduino Uno, nano and Pro Mini should work fine
  // Internal reference voltage for the ATMEGA8 is 2.56 volts, so it should be easy to modify this code for the ATMEGA8
  // The Arduino Mega has two internal voltage references at 1.1v and 2.56v. There's a chance this code could changed to work with the Arduino Mega
  // The voltage is returned in millivolts. So 5000 is 5V, 3300 is 3.3V

  long result;
  // Read 1.1V reference against AVcc
  ADMUX = _BV(REFS0) | _BV(MUX3) | _BV(MUX2) | _BV(MUX1);
  delay(2); // Wait for Vref to settle
  ADCSRA |= _BV(ADSC); // Convert
  while (bit_is_set(ADCSRA, ADSC));
  result = ADCL;
  result |= ADCH << 8;
  result = 1126400L / result; // Back-calculate AVcc in mV
  return result;
}

void setup() {
  pinMode(LED_BUILTIN, OUTPUT); // Setup pin 13 (Arduino's LED pin)
  digitalWrite(LED_BUILTIN, HIGH);

  pinMode(GPS_POWER_PIN, OUTPUT); // Setup pin which controls GPS power via a transistor
  digitalWrite(GPS_POWER_PIN, LOW);

  Serial.begin(UART_SERIAL_BAUD); // HC-12 module on Arduino serial port. Incoming data here will wake up the arduino.
  ss.begin(SS_SERIAL_BAUD);     // GPS module on Arduino ss port (software serial)

  // Save Power by writing all Digital IO to outputs. Remember to not damage any attached devices. Max pin current ~ 20mA
  // Loop for the amount of values in OutputPowerSavingPins array.
  // In this case, sizeof(byte) == 1 so it's not really needed.
  // This is better practice when needing to know the amount of items in an int array.
  for (byte i = 0; i < (sizeof(OutputPowerSavingPins) / sizeof(byte)); i++) {
    pinMode(OutputPowerSavingPins[i], OUTPUT);
  }

  digitalWrite(LED_BUILTIN, LOW);
  delay(500);
}
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

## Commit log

2017-05-26 Added handheld controller, tracking device and more
2017-05-26 Added tracking device files
2017-05-30 Added ability to show the current location on the map
2017-05-30 Added clear map button on pin 8
2017-06-04 Added circuit board files for the tracking device
    For use with KiCad
    [gpsTracker_trackingDevice_circuitBoard.kicad_pcb, gpsTracker_trackingDevice_circuitBoard.sch]
2017-06-05 Added ability to control GPS module's power through a MOSFET
2017-06-11 Changed items shown on TFT screen and it can now read the Vcc voltage
2017-06-11 Added ability to read own Vcc input voltage
2017-06-24 Renamed files and folders
    [trackingDevice_circuitBoard.kicad_pcb, trackingDevice_circuitBoard.sch]
2018-06-09 Replaced ping feature with reading the tracking device Arduino's VCC voltage
2018-06-09 Fixed discontinuity bug with gps:stop
    gps:stopcontinuous changed to gps:stop for tracking device code. Initially the tracking device was listening for the wrong stop message from the handheld controller.
    [trackingDevice.ino]
2018-06-09 Corrected Arduino tracking device pin functions
2018-06-10 Added tracking device circuit board and schematic pictures #2
2018-06-10 Replaced MOSFET with NPN transistor and changed package to TO-126
    [trackingDevice_circuitBoard.kicad_pcb, trackingDevice_circuitBoard.sch]
2018-06-13 Moved circuit board SVGs
2018-07-18 Corrected error in tracking device circuit
2018-08-09 Added veroboard/stripboard drill marks + corrected error in tracking device circuit
    [trackingDevice_circuitBoard.kicad_pcb, trackingDevice_circuitBoard.sch]
2018-08-13 Modified resistor values to be more power-efficient
    [trackingDevice_circuitBoard.kicad_pcb, trackingDevice_circuitBoard.sch]
